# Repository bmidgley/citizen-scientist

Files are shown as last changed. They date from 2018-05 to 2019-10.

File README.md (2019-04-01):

# citizen-scientist

Monitor air quality and automatically share the collected data using inexpensive hardware.

[OpenWest slides](https://docs.google.com/presentation/d/14199zjeJYKTTuAwEFpema6mJRyAuVe0BQ5JEuAFFPP4/edit?usp=sharing) show how to build the project, including slide 24 with wiring explanation.

## Setup

Install [arduino](https://www.arduino.cc/en/Main/Software) 1.8.2 or newer

Install serial driver from [vendor drivers](https://www.silabs.com/products/development-tools/software/usb-to-uart-bridge-vcp-drivers)

Set up [esp8266 runtime](http://esp8266.github.io/Arduino/versions/2.0.0/doc/installing.html) for arduino

Open geothunk.ino in arduino and select board. Tools->Board->NodeMCU 1.0 (ESP-12E Module)

Libraries: sketch->include library->manage libraries
* WiFiManager (0.14.x)
* ArduinoJson (5.x.x)
* PubSubClient (2.x.x)
* "ESP8266 and ESP32 Oled Driver for SSD1306 display" (4.x.x)
* Esp8266TrueRandom (wget https://github.com/marvinroger/ESP8266TrueRandom/archive/master.zip; sketch->include library->Add .zip Library)

Plug in board and choose the port. On mac: Tools->Port->/dev/cu.SLAB_USBtoUART (Reboot and check your USB cable is a full power+data cable if the port isn't available.)

Hit the upload button.

Reboot the board and use your phone to connect to the Geothunk-XXX access point. In the captive portal screen, set the password for your access point. Hit save. There is a [youtube video](https://www.youtube.com/watch?v=-iKyWOWEP4E&t=4s) to show this in practice.

If you're on the same access point as the sensor, you should be able to see graphs for your measurements by clicking its [geothunk.local](http://geothunk.local) mdns link. If mdns isn't working or you have multiple sensors, point a browser at the IP address displayed on the device instead.

Register and agree to share your data with our [agreement](https://docs.google.com/forms/d/e/1FAIpQLScs9sQVZbnWg0XCuS6sA2pAkzf4LLobDE_Wj_pccsHPoGVKmw/viewform)

## Contributors

* Brad Midgley wrote the firmware and built the sensor
* Tim Harper updated the firmware with refactors, overflow protection, improved sensor listener
* Dorian Tolman designed the case

Parts:
* Esp8266 [D-Duino](https://www.aliexpress.com/item/new-NODEMCU-wifi-NodeMCU-forArduino-ESP8266-wemos-for-OLED/32802190441.html)
* [DHT22](https://www.aliexpress.com/wholesale?SearchText=dht22) (3-wire package)
* [PMS3003](https://www.aliexpress.com/item/Laser-PM2-5-DUST-SENSOR-PMS3003-High-precision-laser-dust-concentration-sensor-digital-dust-particles-G3/32371229255.html)

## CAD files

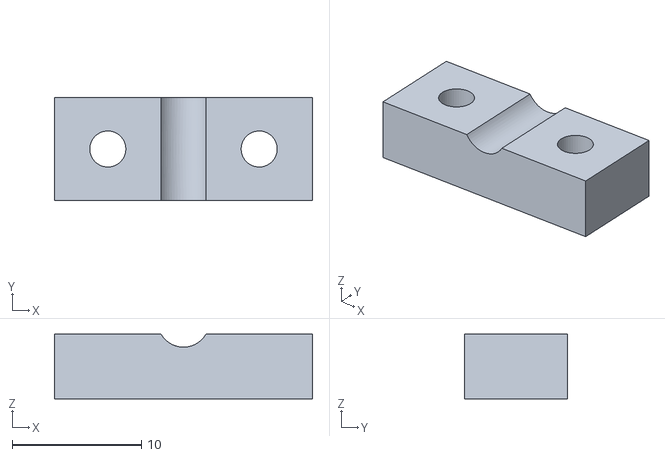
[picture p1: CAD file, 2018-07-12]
prints/v2/cord clamp.stl
20.0 x 8.00 x 5.00

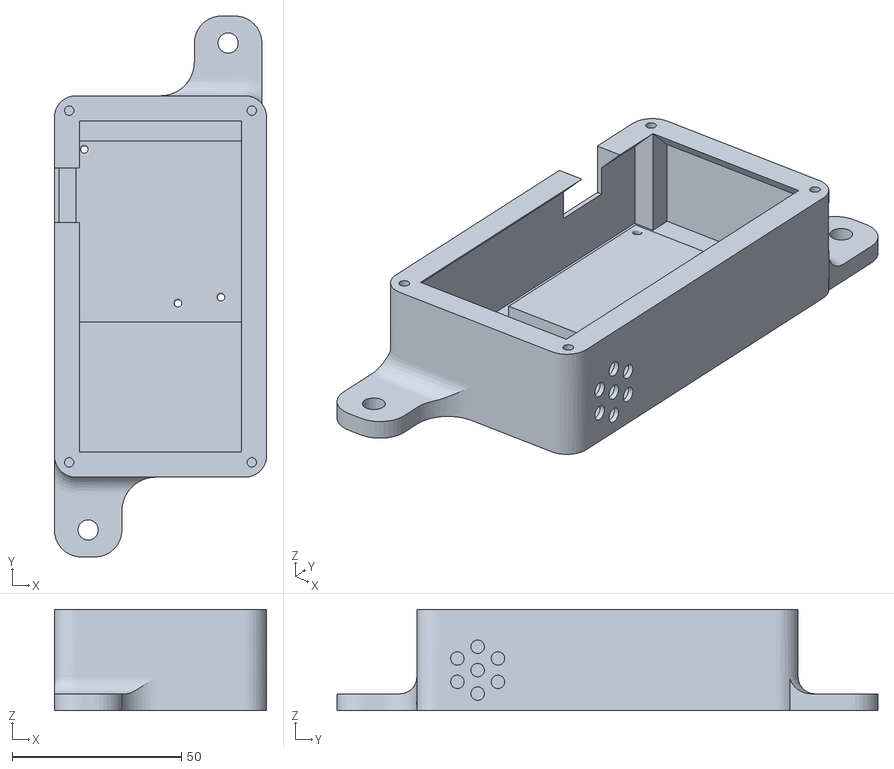
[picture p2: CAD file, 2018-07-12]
prints/v2/base.stl
62.8 x 160.0 x 30.0

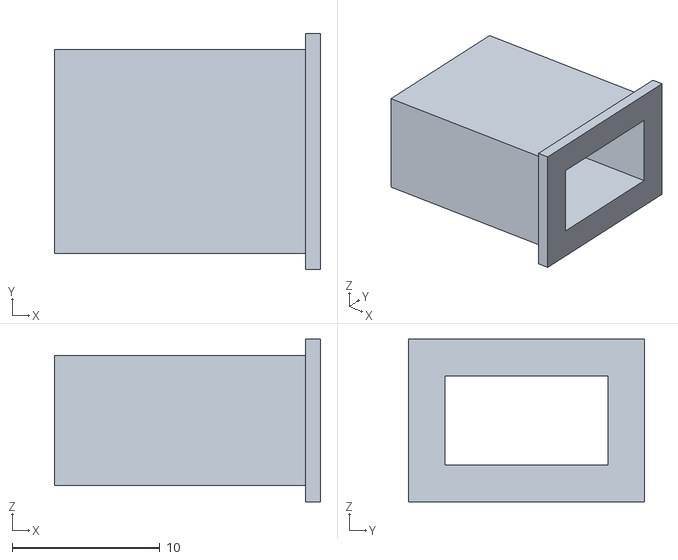
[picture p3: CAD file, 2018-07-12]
prints/v2/vent port.stl
18.0 x 16.0 x 11.0

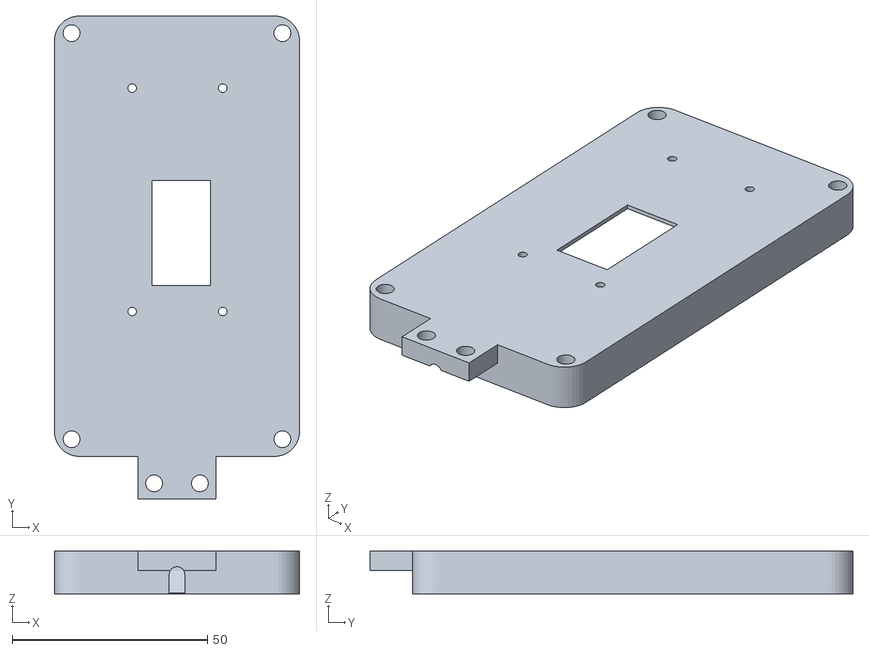
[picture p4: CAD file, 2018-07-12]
prints/v2/top.stl
62.8 x 123.7 x 11.0

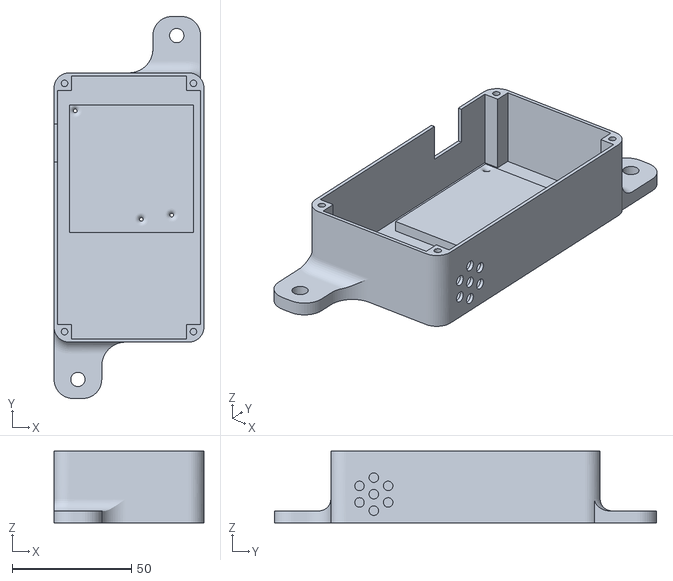
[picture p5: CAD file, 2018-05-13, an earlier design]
prints/v1/AirT Base B.stl
62.8 x 160.0 x 30.0

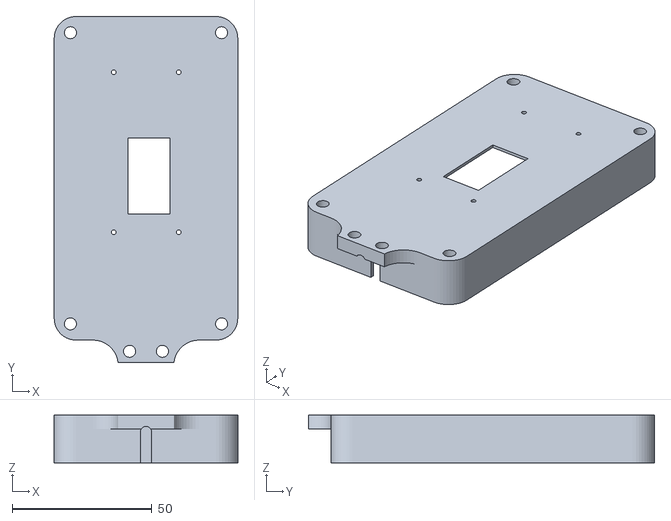
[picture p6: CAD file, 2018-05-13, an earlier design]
prints/v1/AirT Top B.stl
65.6 x 123.6 x 17.0

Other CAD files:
prints/v1/AirT Clamp B.stl
prints/v1/AirT Vent Port BB.stl

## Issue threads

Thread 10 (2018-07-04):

Device reporting 4000+ -- check sensor

bmidgley, 2018-07-04:

bmidgley, 2018-07-08:
Power cycling the device corrected this and it hasn't happened again in a few days. We need to automate the reset.

Closed 2018-07-08.

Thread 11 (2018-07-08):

Reset the sensor in response to a bus message, on a schedule, or when it reports questionable readings

bmidgley, 2018-07-08:

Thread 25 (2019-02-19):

Slow wifi connections time out and go into AP mode

bmidgley, 2019-02-19:
If the wifi connection takes a long time or is unreliable, the device goes into AP mode. Combined with reset cycles causes the device to be unreliable.

There should be a way to lock the wifi or make a long timeout.

I think I'd prefer a configuration option to lock the wifi and never enter AP mode.

If the wifi is locked in via flash memory options, then the program button would be required to reset the wifi and get back into AP mode. This will have to work either when associated or when trying to get associated.

I'm not sure we can get into the wifimanager loop, but we could execute this using a connect timeout combined with a test for the button press if you don't mind holding the button for a while to reset it.

timcharper, 2019-02-19:
I don't think my wifi is unreliable :) I'm not sure why the ESP8266 device reboots occasionally, seems it is just a feature of them :)

bmidgley, 2019-02-19:
It didn't always reboot so often. One of the library updates did this, but I prefer reboot to crash. :/

timcharper, 2019-02-19:
Hmm... I'll monitor the serial for a night and see if I can catch the crash. There might be some stack trace info that will help us pinpoint where it's failing.

I've noticed that really-fast-loops cause the device to crash. Not sure why. `while(1) {}` will crash the device but `while(1) { delay(25); }` will run forever.

timcharper, 2019-02-19:
@bmidgley what would you think if we worked around it? We could have our own code check to see if an AP is persisted, first, and then try and connect to it if so, and then breaking out of the loop in to AP mode if the button is pressed.

For the meantime, I think it seems reasonable to take the case apart and reset if changing AP's; that's not a frequent occurrence. Further we could expose an endpoint which, when hit, reboots the device in AP / config mode.

timcharper, 2019-02-25:
#29 addresses this

Closed 2019-03-07.

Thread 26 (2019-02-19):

Program button can't be pressed using the current 3d printed case

bmidgley, 2019-02-19:
This is a hardware bug! I'll get exact measurements so we can print a pinhole in the right spot and use a pin to hit this button.

I've tried this out and found I broke the microusb connection to the board. So we will need to be sure the board is both connected solidly to the faceplate and also add a little loop in the usb cable so if it does wiggle, it won't put pressure on the connector.

bmidgley, 2019-02-19:
I measure 72.5mm from the left side and 22mm from the top hits the center of the button. We should have a hole that is 1 to 1.5mm diameter. Should be big enough to get a sharp pin in but not so big that we might miss the button.

bmidgley, 2019-02-19:
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

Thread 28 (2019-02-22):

WeMos DHT sensor regression with 7a0b17b

timcharper, 2019-02-22:
After upgrading my WeMos geothunk sensor (the one with the built-in display) to the latest master, I noted that the DHT temperature readings would fail frequently. I traced it down to commit 7a0b17b45ff842c71e1ffa096dcdffaaa0ece5c0, specifically the following change:

```diff
diff --git a/geothunk/geothunk.ino b/geothunk/geothunk.ino
index d2b9a7e..99801b4 100644
--- a/geothunk/geothunk.ino
+++ b/geothunk/geothunk.ino
@@ -296,9 +296,27 @@ void paint_display(long now) {
   }
   display.setTextAlignment(TEXT_ALIGN_RIGHT);
   display.setFont(ArialMT_Plain_10);
-  display.drawString(display.getWidth(), 34, String("1/2/10=") + String(pm1) + String("/") + String(pm2_5) + String("/") + String(pm10));
-  display.drawString(display.getWidth(), 44, String(humidity) + String("%h"));
-  display.drawString(display.getWidth(), 54, String(temperature) + String("°C"));
+
+  String pmValues = String("1/2/10=");
+  String humidityString;
+  String temperatureString;
+
+  if (pmOverdue(now))
+    pmValues = pmValues + String("E/E/E");
+  else
+    pmValues = pmValues + String(pm1) + String("/") + String(pm2_5) + String("/") + String(pm10);
+
+  if (dhtOverdue(now)) {
+    humidityString = String("E");
+    temperatureString = String("E");
+  } else {
+    humidityString = String(humidity);
+    temperatureString = String(temperature);
+  }
+  display.drawString(display.getWidth(), 34, pmValues);
+  display.drawString(display.getWidth(), 44, humidityString + String("%h"));
+  display.drawString(display.getWidth(), 54, temperatureString + String("°C"));
+
   display.setTextAlignment(TEXT_ALIGN_LEFT);
   if (hours < 24)
     uptime = String(hours) + String("h");
```

timcharper, 2019-02-22:
I don't fully understand why this is broken, but I suspect it has something to do with `String pmValues = String("1/2/10=");` followed by `pmValues = pmValues + ...`. Perhaps the String class is doing some auto management of memory when it is freed from the stack, and this pattern of usage is causing it to fail.

timcharper, 2019-02-22:
This works:

```diff
diff --git a/geothunk/geothunk.ino b/geothunk/geothunk.ino
index d2b9a7e..ca401a1 100644
--- a/geothunk/geothunk.ino
+++ b/geothunk/geothunk.ino
@@ -296,9 +296,27 @@ void paint_display(long now) {
   }
   display.setTextAlignment(TEXT_ALIGN_RIGHT);
   display.setFont(ArialMT_Plain_10);
-  display.drawString(display.getWidth(), 34, String("1/2/10=") + String(pm1) + String("/") + String(pm2_5) + String("/") + String(pm10));
-  display.drawString(display.getWidth(), 44, String(humidity) + String("%h"));
-  display.drawString(display.getWidth(), 54, String(temperature) + String("°C"));
+
+  char buffer[64];
+
+  if (pmOverdue(now))
+    strncpy(buffer, "1/2/10=E/E/E", sizeof(buffer));
+  else
+    snprintf(buffer, sizeof(buffer), "1/2/10=%d/%d/%d", pm1, pm2_5, pm10);
+  display.drawString(display.getWidth(), 34, buffer);
+
+  if (dhtOverdue(now)) {
+    strncpy(buffer, "E", sizeof(buffer));
+  } else {
+    snprintf(buffer, sizeof(buffer), "%d%%h", humidity);
+  }
+  display.drawString(display.getWidth(), 44, buffer);
+
+  if (!dhtOverdue(now)) {
+    snprintf(buffer, sizeof(buffer), "%d°C", temperature);
+  }
+  display.drawString(display.getWidth(), 54, buffer);
+
   display.setTextAlignment(TEXT_ALIGN_LEFT);
   if (hours < 24)
     uptime = String(hours) + String("h");
```

bmidgley, 2019-02-22:
Nice find. It is unnerving to have a really complete and complex SDK and not know if it's safe to use. Will have to do it carefully.

timcharper, 2019-02-22:
It's not a regression with 7a0b17b, it's the hardware. Probably some timing issue. I found that simply increasing the tolerance for a "faster" high pull allows it to measure consistently.

https://github.com/timcharper/SimpleDHT/commit/44d730c19a1cbf79668dddef0c92bb6aad8109bd

timcharper, 2019-02-22:
https://github.com/winlinvip/SimpleDHT/issues/35

timcharper, 2019-02-25:
I'm closing this; I tried with a new board and a new DHT22 sensor, and the issue is gone. It may have just been the board. It is nice to know that reducing the timing threshold in SimpleDHT from 30 to 20 when seeing an error `SimpleDHTErrStartLow`.

Closed 2019-02-25.

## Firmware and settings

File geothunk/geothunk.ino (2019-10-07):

//#define SPI_DISPLAY
//#define SH1106_DISPLAY
//#define NO_AUTO_SWAP
//#define DEBUG
#ifdef DEBUG
#define NO_AUTO_SWAP
#endif

#ifdef SPI_DISPLAY
#define NO_AUTO_SWAP
#endif

#include <FS.h>
#include <ESP8266WiFi.h>
#include <DNSServer.h>
#include <ESP8266WebServer.h>
#include <WiFiManager.h>
#include <PubSubClient.h>
#include "SSD1306Spi.h"
#include "SH1106.h"
#include "SSD1306.h"
#include "ESP8266TrueRandom.h"
#include <ArduinoJson.h>
#include <ESP8266mDNS.h>
#include <ArduinoOTA.h>
#include <ESP8266httpUpdate.h>
#include <WiFiClientSecure.h>
#include <time.h>
#include <Servo.h>
#include "PmsSensorReader.h"
#include "Presentation.h"
#include "UniversalDHT.h"

int pinDHT = D3;
UniversalDHT dht(pinDHT);

// use arduino library manager to get libraries
// sketch->include library->manage libraries
// WiFiManager, ArduinoJson, PubSubClient, ArduinoOTA, "ESP8266 and ESP32 Oled Driver for SSD1306 display"
// wget https://github.com/marvinroger/ESP8266TrueRandom/archive/master.zip
// sketch->include library->Add .zip Library and select master.zip

#define DEFAULT_MDNS_NAME "geothunk"
#define FLASH_BUTTON_PIN 0 // note, this is shared with D3!
#define LED_PIN D4
#define PULSE_PIN D8

bool shouldSaveConfig = false;
unsigned long lastSample = 0;
unsigned long lastReport = 0;
unsigned long lastPmReading = 0;
unsigned long lastDHTReading = 0;
unsigned long lastSwap = 0;
long nextFrame = 0; // Time at which the next frame should be drawn
char msg[200] = "";
char errorMsg[200] = "";
int disconnects = 0;

char mqtt_server[40] = "mqtt.geothunk.com";
char mqtt_port[6] = "8080";
char uuid[64] = "";
char gps_port[10] = "";
char ota_password[10] = "";
char mdns_name[40] = DEFAULT_MDNS_NAME;

char particle_topic_name[128];
char error_topic_name[128];

int sampleGap = 4 * 1000;
int reportGap = 60 * 1000;
int reportExpectedDurationMs = sampleGap * 5;
int byteGPS = -1;
char linea[300] = "";
char comandoGPR[] = "$GPRMC";
int cont = 0;
int bien = 0;
int conta = 0;
int indices[13];
int lats = 1;
int latw = 0;
int latf = 0;
int lngs = 1;
int lngw = 0;
int lngf = 0;

WiFiClientSecure *tcpClient;
PubSubClient *client;
ESP8266WebServer *webServer;
PmsSensorReader pmsSensor;

#ifdef SPI_DISPLAY
SSD1306Spi display(D8, D1, D2); // rst n/c, dc D1, cs D2, clk D5, mosi/di/si D7
#else
#ifdef SH1106_DISPLAY
SH1106 display(0x3c, D1, D2);
#else
SSD1306 display(0x3c, 5, 4);
#endif
#endif

AirData airData;
Presentation presentation(&display, &airData);
Servo myservo;

const char* serverIndex = "<html><head><script type='text/javascript' src='https://cdnjs.cloudflare.com/ajax/libs/smoothie/1.34.0/smoothie.js'></script> <script type='text/javascript' src='https://cdnjs.cloudflare.com/ajax/libs/jquery/3.2.1/jquery.js'></script> <script type='text/Javascript'> \
var sc = new SmoothieChart({ responsive: true, millisPerPixel: 1000, labels: { fontSize: 30, precision: 0 }, grid: { fillStyle: '#6699ff', millisPerLine: 100000, verticalSections: 10 }, yRangeFunction: function(r) { return { min: 0, max: Math.max(30, 10*Math.ceil(0.09 * r.max)) } } }); \
var line1 = new TimeSeries(); var line2 = new TimeSeries(); var line3 = new TimeSeries(); \
sc.addTimeSeries(line1, { strokeStyle:'rgb(180, 50, 0)', fillStyle:'rgba(180, 50, 0, 0.4)', lineWidth:3 }); \
sc.addTimeSeries(line2, { strokeStyle:'rgb(255, 0, 0)', fillStyle:'rgba(255, 0, 0, 0.4)', lineWidth:3 }); \
sc.addTimeSeries(line3, { strokeStyle:'rgb(255, 50, 0)', fillStyle:'rgba(255, 50, 0, 0.4)', lineWidth:3 }); \
$(document).ready(function() { sc.streamTo(document.getElementById('graphcanvas1')); }); \
setInterval(function() { $.getJSON('/stats',function(data){ line1.append(Date.now(), data.pm2); line2.append(Date.now(), data.pm1); if(data.pm10 < 3*data.pm2) line3.append(Date.now(), data.pm10); }); }, 2000); \
</script></head><body>  <canvas id='graphcanvas1' style='width:100%%; height:75%%;'></canvas><p>Register device <a href='https://geothunk.com/devices?d=%s'>online</a>.</p></body></html>";

t_httpUpdate_return update() {
  return ESPhttpUpdate.update("http://updates.geothunk.com/updates/geothunk-" VERSION ".ino.bin");
}

void mqttCallback(char* topic, byte* payload, unsigned int length) {
#ifdef DEBUG
  Serial.print("Message arrived [");
  Serial.print(topic);
  Serial.print("] ");
  for (int i = 0; i < length; i++) {
    char receivedChar = (char)payload[i];
    Serial.print(receivedChar);
  }
  Serial.println();
#endif
}

int mqttConnect() {
  if (WiFi.status() != WL_CONNECTED) {
    return 0;
  }

  if (client->connected()) {
    disconnects = 0;
    return 1;
  }

  if (client->connect(uuid)) {
    client->subscribe("clients");
    return 1;
  } else {
    disconnects += 1;
    return 0;
  }
}

void saveConfigCallback () {
  shouldSaveConfig = true;
}

void to_degrees(char *begin, char *end, int &whole, int &decimal) {
  char copied[20];
  float result;
  strncpy(copied, begin, 10);
  copied[end - begin] = '\0';
  float nmea = atof(copied);
  whole = (int)(nmea / 100);
  nmea -= 100 * whole;
  decimal = (int)(nmea * ( 10000.0 / 60.0));
}

int handle_gps_byte(char byteGPS) {
  linea[conta] = byteGPS;
  conta++;
  if (byteGPS == 13 || conta >= 300) {
    cont = 0;
    bien = 0;
    for (int i = 1; i < 7; i++) {
      if (linea[i] == comandoGPR[i - 1]) {
        bien++;
      }
    }
    if (bien == 6) {
      for (int i = 0; i < 300; i++) {
        if (linea[i] == ',' && cont < 13) {
          indices[cont] = i;
          cont++;
        }
        if (linea[i] == '*') {
          indices[12] = i;
          cont++;
        }
      }
      for (int i = 0; i < 12; i++) {
        switch (i) {
          case 2:
            to_degrees(linea + 1 + indices[i], linea + indices[i + 1], latw, latf);
            break;
          case 3:
            lats = linea[indices[i] + 1] == 'N' ? 1 : -1;
            break;
          case 4:
            to_degrees(linea + 1 + indices[i], linea + indices[i + 1], lngw, lngf);
            break;
          case 5:
            lngs = linea[indices[i] + 1] == 'E' ? 1 : -1;
            break;
        }
      }
    }
    conta = 0;
    for (int i = 0; i < 300; i++) {
      linea[i] = ' ';
    }
  }
}

bool pmOverdue(unsigned long now) {
  return (now - lastPmReading) > reportExpectedDurationMs;
}

bool dhtOverdue(long now) {
  return (now - lastDHTReading) > reportExpectedDurationMs;
}



void handleGPS() {
  if (tcpClient->connected() && tcpClient->available()) handle_gps_byte(tcpClient->read());
}

void measureDHT() {
  float temperature, humidity = 0;
  UniversalDHT::Response response = dht.read(&temperature, &humidity);
#ifdef DEBUG
  if(response.error) {
    Serial.printf("Read DHTxx failed t=%d err=%d\n", response.time, response.error);
  } else {
    Serial.print("Sample OK: ");
    Serial.print((float)temperature); Serial.print(" *C, ");
    Serial.print((float)humidity); Serial.println(" RH%");
    Serial.println();
  }
#endif
  if (!response.error) {
    lastDHTReading = millis();
    airData.humidity = humidity;
    airData.temperature = temperature;
    airData.tempHumidityStatus = AirData_Ok;
  }

  presentation.recordGraphTemperature();
}

boolean loadConfig() {
  if (SPIFFS.begin()) {
    Serial.println("mounted file system");
    if (SPIFFS.exists("/config.json")) {
      Serial.println("found /config.json");
      File configFile = SPIFFS.open("/config.json", "r");
      if (configFile) {
        Serial.println("reading /config.json");
        size_t size = configFile.size();
        std::unique_ptr<char[]> buf(new char[size]);

        configFile.readBytes(buf.get(), size);
        DynamicJsonBuffer jsonBuffer;
        JsonObject& json = jsonBuffer.parseObject(buf.get());
        json.printTo(Serial);
        if (json.success()) {
#ifdef DEBUG
          Serial.println("\nparsed json");
#endif

          if (json.is<char*>("mqtt_server")) strncpy(mqtt_server, json["mqtt_server"].as<char*>(), sizeof(mqtt_server));
          if (json.is<char*>("mqtt_port")) strncpy(mqtt_port, json["mqtt_port"].as<char*>(), sizeof(mqtt_port));
          if (json.is<char*>("mdns_name")) strncpy(mdns_name, json["mdns_name"].as<char*>(), sizeof(mdns_name));
          if (json.is<char*>("gps_port")) strncpy(gps_port, json["gps_port"].as<char*>(), sizeof(gps_port));
          if (json.is<char*>("ota_password")) strncpy(ota_password, json["ota_password"].as<char*>(), sizeof(ota_password));
          if (json.is<char*>("uuid")) strncpy(uuid, json["uuid"].as<char*>(), sizeof(uuid));
          return true;
        } else {
          Serial.println("failed to load json config");
        }
      }
    }
  } else {
    Serial.println("failed to mount FS");
  }
  return false;
}

void configureAP() {
  char ap_name[64] = "";
  byte uuidNumber[16];
  byte uuidCode[16];
  WiFiManager wifiManager;

  ESP8266TrueRandom.uuid(uuidCode);
  ESP8266TrueRandom.uuidToString(uuidCode).toCharArray(ota_password, 7);

  WiFiManagerParameter custom_mqtt_server("server", "mqtt server", mqtt_server, sizeof(mqtt_server));
  WiFiManagerParameter custom_mqtt_port("port", "mqtt port", mqtt_port, sizeof(mqtt_port));
  WiFiManagerParameter custom_mdns_name("name", "Hostname (optional)", mdns_name, sizeof(mdns_name));
  WiFiManagerParameter custom_gps_port("gps_port", "GPS server port (optional)", gps_port, sizeof(gps_port));
  WiFiManagerParameter custom_ota_password("ota_password", "OTA password (optional)", ota_password, sizeof(ota_password));

  wifiManager.setSaveConfigCallback(saveConfigCallback);

  wifiManager.addParameter(&custom_mqtt_server);
  wifiManager.addParameter(&custom_mqtt_port);
  wifiManager.addParameter(&custom_mdns_name);
  wifiManager.addParameter(&custom_gps_port);
  if (*ota_password == 0) {
    Serial.println("generating ota_password");
    wifiManager.addParameter(&custom_ota_password);
    saveConfigCallback();
  }
  if (*uuid == 0) {
    Serial.println("generating uuid");
    ESP8266TrueRandom.uuid(uuidNumber);
    ESP8266TrueRandom.uuidToString(uuidNumber).toCharArray(uuid, 64);
    saveConfigCallback();
  }

  snprintf(ap_name, sizeof(ap_name), "Geothunk-%d", ESP8266TrueRandom.random(100, 1000));
  Serial.printf("Configure by connecting to AP %s\n", ap_name);

  wifiManager.setTimeout(600);
  wifiManager.setBreakAfterConfig(true);
  presentation.paintServingAp(String(ap_name));

  digitalWrite(LED_PIN, LOW);
  boolean connected = false;

  while (!connected) {
    connected = wifiManager.startConfigPortal(ap_name);
    Serial.println("stored wifi connected");
    WiFi.setAutoConnect(true);

    strcpy(mqtt_server, custom_mqtt_server.getValue());
    strcpy(mqtt_port, custom_mqtt_port.getValue());
    strncpy(mdns_name, custom_mdns_name.getValue(), sizeof(mdns_name));
    strcpy(gps_port, custom_gps_port.getValue());

    if (shouldSaveConfig) {
      shouldSaveConfig = false;
      Serial.println("saving config");
      DynamicJsonBuffer jsonBuffer;
      JsonObject& json = jsonBuffer.createObject();
      json["mqtt_server"] = mqtt_server;
      json["mqtt_port"] = mqtt_port;
      json["mdns_name"] = mdns_name;
      json["gps_port"] = gps_port;
      json["ota_password"] = ota_password;
      json["uuid"] = uuid;

      File configFile = SPIFFS.open("/config.json", "w");
      if (!configFile) {
        Serial.println("failed to open config file for writing");
      }

      json.printTo(Serial);
      Serial.println("");
      json.printTo(configFile);
      configFile.close();
      if (WiFi.status() != WL_CONNECTED) {
        /* WiFi manager on NodeMCU seems to always fail to connect to the network after successful configuration, no matter how
         * long you wait. It should connect after a reboot resolves.
         */
        ESP.restart();
      }
    }

    measureDHT();

  };

  digitalWrite(LED_PIN, HIGH);
}

int timeInState(int pin, int state, int timeout) {
  if (digitalRead(pin) != state)
    return 0;

  unsigned long start = millis();
  unsigned long now = start;
  while ((digitalRead(pin) == state) && ((now - start) < timeout)) {
    yield(); // appease the watchdog
    now = millis();
  }
  return now - start;
}

void setup() {
  airData.pmStatus = AirData_Uninitialized;
  airData.tempHumidityStatus = AirData_Uninitialized;

  Serial.begin(9600);
  Serial.println("\n Starting");
  pinMode(FLASH_BUTTON_PIN, INPUT);
  pinMode(LED_PIN, OUTPUT);
  pinMode(PULSE_PIN, OUTPUT);
  tone(PULSE_PIN, 40);
  WiFi.printDiag(Serial);
  myservo.attach(D0);

  display.init();
#ifndef SPI_DISPLAY
  display.flipScreenVertically();
#endif
  display.setContrast(255);
  display.clear();


  boolean configWasLoaded = loadConfig();

  if (configWasLoaded && ((WiFi.SSID() != NULL) && (WiFi.SSID().length() > 0))) {
    Serial.print("Reconnecting to last saved access point, ");
    Serial.println(WiFi.SSID());
    //trying to fix connection in progress hanging
    WiFi.begin();
    presentation.paintConnectingWifi();
    while (WiFi.status() != WL_CONNECTED) {
      yield(); // prevent watchdog from restarting controller
      if (timeInState(FLASH_BUTTON_PIN, LOW, 15000) >= 1000) {
        Serial.println("Resetting WiFi credentials to put back in config mode");
        WiFi.disconnect();
        delay(500);
        ESP.restart();
      };
    }
    digitalWrite(LED_PIN, HIGH);
  } else {
    configureAP();
  }

  presentation.paintConnectingMqtt(millis());

  int mqtt_port_int = strtoul(mqtt_port, NULL, 10);
  Serial.printf("Connecting to mqtt on %s, port %i\n", mqtt_server, mqtt_port_int);
  client = new PubSubClient(mqtt_server, mqtt_port_int, *(new WiFiClient()));
  client->setCallback(mqttCallback);
  mqttConnect();

  for (int i = 0; i < 300; i++) {
    linea[i] = ' ';
  }
  tcpClient = new WiFiClientSecure();
  tcpClient->connect(WiFi.gatewayIP(), atoi(gps_port));
  snprintf(particle_topic_name, sizeof(particle_topic_name), "%s/particles", uuid);
  snprintf(error_topic_name, sizeof(error_topic_name), "%s/errors", uuid);

  Serial.printf("publishing data on %s\n", particle_topic_name);
  Serial.printf("publishing errors on %s\n", error_topic_name);

  Serial.printf("ota_password is %s\n", ota_password);
#ifndef DEBUG
  ArduinoOTA.setPassword(ota_password);
#endif

  ArduinoOTA.onProgress([](unsigned int progress, unsigned int total) {
    Serial.printf("Progress: %u%%\r", (progress / (total / 100)));
  });
  ArduinoOTA.onError([](ota_error_t error) {
    Serial.printf("Error[%u]: ", error);
    if (error == OTA_AUTH_ERROR) Serial.println("Auth Failed");
    else if (error == OTA_BEGIN_ERROR) Serial.println("Begin Failed");
    else if (error == OTA_CONNECT_ERROR) Serial.println("Connect Failed");
    else if (error == OTA_RECEIVE_ERROR) Serial.println("Receive Failed");
    else if (error == OTA_END_ERROR) Serial.println("End Failed");
  });
  ArduinoOTA.begin();

  MDNS.begin(mdns_name);
  MDNS.addService("http", "tcp", 80);
  webServer = new ESP8266WebServer(80);
  webServer->onNotFound([]() {
    webServer->send(404, "text/plain", "File not found");
  });
  webServer->on("/", HTTP_GET, []() {
    char response[1600];
    webServer->sendHeader("Connection", "close");
    webServer->sendHeader("Access-Control-Allow-Origin", "*");
    snprintf(response, sizeof(response), serverIndex, uuid);
    webServer->send(200, "text/html", response);
  });
  webServer->on("/stats", HTTP_GET, []() {
    webServer->sendHeader("Connection", "close");
    webServer->sendHeader("Access-Control-Allow-Origin", "*");
    webServer->send(200, "application/json", msg);
  });
  webServer->begin();

  configTime(3 * 3600, 0, "pool.ntp.org", "time.nist.gov");

#ifndef NO_AUTO_SWAP
  Serial.swap();
#endif

}

void pmsSensorLoop(long now) {
#ifdef DEBUG
  if (!Serial.available())
    return;

  Serial.printf("serial: ");
#endif

  while(Serial.available()) {
    unsigned char value = Serial.read();
#ifdef DEBUG
    Serial.printf("%x ", value);
#endif
    if (pmsSensor.offer(value)) {
      lastPmReading = now;
      airData.pm1 = pmsSensor.pm1;
      airData.pm2_5 = pmsSensor.pm2_5;
      airData.pm10 = pmsSensor.pm10;
      airData.pmStatus = AirData_Ok;
      presentation.recordGraphPm2();
    }
  }

#ifdef DEBUG
  Serial.printf("\n");
#endif
}

void loop() {
  handleGPS();
  ArduinoOTA.handle();
  webServer->handleClient();
  client->loop();

  long now = millis();
  pmsSensorLoop(now);

  if (now >= nextFrame) {
    if (dhtOverdue(now)) {
      airData.tempHumidityStatus = AirData_Stale;
    } else {
      airData.tempHumidityStatus = AirData_Ok;
    }

    if (pmOverdue(now)) {
      airData.pmStatus = AirData_Stale;
    } else {
      airData.pmStatus = AirData_Ok;
    }

    nextFrame = now + 64; // 1000 / 64 = ~15 fps
    presentation.paintDisplay(now);
  }

  if (now - lastSample > sampleGap) {
    lastSample = now;

    measureDHT();

    myservo.write(map(pmsSensor.pm2_5, 0, 30, 180, 0));

    if (!tcpClient->connected() && atoi(gps_port) > 0) tcpClient->connect(WiFi.gatewayIP(), atoi(gps_port));

    long earlierLastReading = lastPmReading < lastDHTReading ? lastPmReading : lastDHTReading;
    snprintf(msg, sizeof(msg), "{\"pm2\":%u,\"pm1\":%u,\"pm10\":%u,\"l\":%s%d.%d,\"n\":%s%d.%d,\"u\":%u,\"t\":%0.1f,\"h\":%0.1f}",
             pmsSensor.pm2_5, pmsSensor.pm1, pmsSensor.pm10, lats > 0 ? "" : "-", latw, latf, lngs > 0 ? "" : "-", lngw, lngf, earlierLastReading / 60000, airData.temperature, airData.humidity);

    *errorMsg = 0;
    if (lastSample - lastPmReading > 30000) {
      snprintf(errorMsg, sizeof(errorMsg), "{\"lastSample\": %u, \"lastPmReading\": %u}", lastSample, lastPmReading);
#ifndef NO_AUTO_SWAP
      if (now - lastSwap > 60000) {
        Serial.println("swapping from here");
        Serial.flush();
        Serial.swap();
        Serial.println("swapped to here");
        lastSwap = now;
      }
#endif
    }
  }

  if (now - lastReport > reportGap && mqttConnect()) {
    lastReport = now;

    if(!client->publish(particle_topic_name, msg))
      Serial.printf("failed to send %s", msg);
    if (*errorMsg) {
      client->publish(error_topic_name, errorMsg);
      *errorMsg = '\0';
    }
  }

  // restart once per day
  if (now > 1000 * 60 * 60 * 24) {
    ESP.restart();
  }
}

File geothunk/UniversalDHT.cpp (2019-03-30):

/*
  Universal auto-detecting DHT11 or DHT22 sensor.

  Copyright (c) 2019 Tim Harper

  https://github.com/timcharper

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
  THE SOFTWARE IS PROVIDED "AS IS", WITHOUT WARRANTY OF ANY KIND, EXPRESS OR
  IMPLIED, INCLUDING BUT NOT LIMITED TO THE WARRANTIES OF MERCHANTABILITY,
  FITNESS FOR A PARTICULAR PURPOSE AND NONINFRINGEMENT. IN NO EVENT SHALL THE
  AUTHORS OR COPYRIGHT HOLDERS BE LIABLE FOR ANY CLAIM, DAMAGES OR OTHER
  LIABILITY, WHETHER IN AN ACTION OF CONTRACT, TORT OR OTHERWISE, ARISING FROM,
  OUT OF OR IN CONNECTION WITH THE SOFTWARE OR THE USE OR OTHER DEALINGS IN THE
  SOFTWARE.
*/

/**
 * This module is a rewrite of SimpleDHT: https://github.com/winlinvip/SimpleDHT
 *
 * SimpleDHT is Copyright (c) 2016-2017 winlin, and is also licensed MIT
 */

#include "UniversalDHT.h"

UniversalDHT::UniversalDHT(int pin) {
  this->pin = pin;
}

bool waitWhileValue(int pin, byte value) {
  unsigned long time_start = micros();
  long time = 0;

  while (digitalRead(pin) == value) {
    delayMicroseconds(6);
    time = micros() - time_start;
    if ((time < 0) || (time > VALUE_TIMEOUT)) {
      return false;
    }
  }
  return true;
}

UniversalDHT::Response parseDHT11(short rawTemperature, short rawHumidity, float* ptemperature, float* phumidity) {
  UniversalDHT::Response ret = {UniversalDHT::Response::success, 0};

  if (ptemperature) {
    *ptemperature = (float)(rawTemperature>>8);
  }
  if (phumidity) {
    *phumidity = (float)(rawHumidity>>8);
  }
  return ret;
}

UniversalDHT::Response parseDHT22(short rawTemperature, short rawHumidity, float* ptemperature, float* phumidity) {
  UniversalDHT::Response ret = {UniversalDHT::Response::success, 0};

  if (ptemperature) {
    *ptemperature = (float)((rawTemperature & 0x8000 ? -1 : 1) * (rawTemperature & 0x7FFF)) / 10.0;
  }
  if (phumidity) {
    *phumidity = (float)rawHumidity / 10.0;
  }

  return ret;
}

UniversalDHT::Response UniversalDHT::read(float* ptemperature, float* phumidity) {
  RawReading reading;
  Response ret = sample(&reading);
  if (ret.error) return ret;


  byte expect = reading.humidity16 + reading.humidity8 + reading.temperature16 + reading.temperature8;
  if (reading.checksum != expect) {
    ret.error = UniversalDHT::Response::errDataChecksum;
    return ret;
  }

  short rawHumidity = ((short)reading.humidity16 << 8) | reading.humidity8;;
  short rawTemperature = ((short)reading.temperature16 << 8) | reading.temperature8;;

  /**
   * DHT11 min humidity sensitivity is 20 and is reported as 20, 0
   * DHT22 max humidity is 100 and is reported as 3, 232
   * A value of 4, x or greater can be safely assumed as a DHT11 reading (it would be 102.4% humidity interpretted as DHT22)
   */
  if (reading.humidity16 > 4)
    return parseDHT11(rawTemperature, rawHumidity, ptemperature, phumidity);
  else
    return parseDHT22(rawTemperature, rawHumidity, ptemperature, phumidity);
}


inline int advance(long &last_frame, long &next_frame) {
  last_frame = next_frame;
  next_frame = micros();
  return next_frame - last_frame;
}

UniversalDHT::Response UniversalDHT::sample(RawReading *reading) {
  long lf, nf = 0;
  Response ret = {Response::success, 0};

  // https://www.sparkfun.com/datasheets/Sensors/Temperature/DHT22.pdf
  pinMode(pin, OUTPUT);
  digitalWrite(pin, LOW);            // Step 1: send start signal
  delay(20);                         // DHT11: at least 18ms; DHT22: at least 1ms

  // Pull high and set to input, before wait 40us.
  digitalWrite(pin, HIGH);           // 2.
  delayMicroseconds(25);             // specs [2]: 20-40us

  advance(lf, nf);

  // pin_mode change can take variable amounts of time to return; starting our timer measurement before calling pinMode
  // is paramount for reliable timings
  pinMode(pin, INPUT);

  // DHT11 starting:
  //    1. PULL LOW 80us
  //    2. PULL HIGH 80us
  waitWhileValue(pin, LOW);
  int t = advance(lf, nf);
  if (t < 30) {                    // specs [2]: 80us
    ret.time = t;
    ret.error = Response::errStartLow;
    return ret;
  }

  waitWhileValue(pin, HIGH);             // 2.
  t = advance(lf, nf);
  if (t < 50) {                    // specs [2]: 80us
    ret.time = t;
    ret.error = Response::errStartHigh;
    return ret;
  }


  byte *ptr = (byte *)reading;
  // DHTxx data transmission:
  //    1. 1bit start, PULL LOW 50us
  //    2. PULL HIGH:
  //         - 26-28us, bit(0)
  //         - 70us, bit(1)
  for (byte byte_idx = 0; byte_idx < sizeof(RawReading); byte_idx ++) {
    ptr = (byte*)reading + byte_idx;
    *ptr = 0;
    for (signed char bit_idx = 7; bit_idx >= 0; bit_idx --) {
      waitWhileValue(pin, LOW);          // 1.
      t = advance(lf, nf);
      if (t < 24) {                    // specs says: 50us
        ret.time = t;
        ret.error = Response::errDataLow;
        return ret;
      }

      // read a bit
      waitWhileValue(pin, HIGH);              // 2.
      t = advance(lf, nf);
      if (t < 11) {                     // specs say: 26-28us
        ret.time = t;
        ret.error = Response::errDataRead;
        return ret;
      }

      *ptr = *ptr | ((t > 40 ? 1 : 0) << bit_idx);     // specs: 26-28us -> 0, 70us -> 1
    }
  }

  // DHT11 EOF:
  //    1. PULL LOW 50us.
  waitWhileValue(pin, LOW);                     // 1.
  t = advance(lf, nf);
  if (t < 24) {                           // specs say: 50us
    ret.time = t;
    ret.error = Response::errDataEOF;
  }

  return ret;
}

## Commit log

2017-05-06 reading from air sensor
2017-05-21 reconfigure requires a long buttonpress
2017-05-23 fix topic name, add error topic
    [geothunk.ino]
2017-07-12 print topic names
2017-07-18 create ota password, reset instructions, less update poll info
    [geothunk.ino]
2017-07-24 swap to the second port if no data arrives for alternate wiring
    [geothunk.ino]
2017-07-31 display temperature
2017-07-31 shorten message so mqtt delivers
    [geothunk.ino]
2017-08-18 basic os update button
2017-12-25 fix reversed logic for report gap
    [geothunk.ino]
2017-12-25 shorten message to fit in limit
    [geothunk.ino]
2017-12-25 do not reboot to reconnect to bus
    [geothunk.ino]
2017-12-27 print data on http request; pm2.5 is first; better flash reset
    [geothunk.ino]
2018-01-02 spi display support
2018-01-02 flag all debug, no swap option
    [geothunk.ino]
2018-01-02 move temperature sensor to D1 (hardware change!)
2018-01-02 fix compile break for i2c display
    [geothunk.ino]
2018-01-05 use d3 for temp sensor
2018-02-25 flip screen to fit new printed case
    [geothunk.ino]
2018-03-05 do not flip spi display
    [geothunk.ino]
2018-04-09 Revert "turn off wifi diag"
    This reverts commit dc63b3a52ef62be60ffff7ebd0a74f5d00d60ecc.
    [geothunk.ino]
2018-05-13 Add 3d prints and credit
    [AirT Base B.stl, AirT Clamp B.stl, AirT Top B.stl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]
2018-06-28 Set 10 minute timeout to fix config mode
    [geothunk.ino]
2018-06-28 Drive a servo connected to d0 to turn a dial
2018-06-28 Update README.md
    explain driver setup
2018-07-06 Debug sensor
2018-07-12 v2 prints
    [base.stl, cord clamp.stl, top.stl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]
2018-10-26 Bump version and make on-device graph go no smaller than 15ug/m3 scale
2018-12-24 pulse pin
2018-12-26 Add library versions for dependencies
    6.x.x version of ArduinoJSON will not compile
2018-12-29 Newer lcd library flips screen for us
    [geothunk.ino]
2018-12-31 Surface errors in spi display
    If we haven't received a valid reading for PMS3003 or from DHT11, then show E's on the display.
    Also, "u" returned stat is the earliest last update of both DHT11 or PMS3003; malfunction of either sensor will prevent
    the number from progressing.
    [geothunk.ino]
2019-01-01 Use sizeof with snprintf
    Also, fix implicit widening / narrowing for byteGPS
    [geothunk.ino]
2019-01-05 Revert "Newer lcd library flips screen for us"
    This reverts commit cb45a926f348bbc1108baa7a86e9c05a396e7885.
    [geothunk.ino]
2019-01-05 Configure mdns name at setup; remove reconfigure timer
2019-01-15 Use PmsSensorReader class
    One issue with the old reader approach was it expected the data to be
    all available, in a buffer, all at once. There are situations where
    this may not be true. The PmsSensorReader will better handle those
    situations.
    [geothunk.ino]
2019-02-06 Only paint frame when needed
2019-02-06 Turn the LED off when we've connected
2019-02-20 Fix issue in which uuid and mqtt_server config parameters were not read
    Checking truthiness of json["mqtt_server"] and json["uuid"] did not work as expected; if would evaluate to false even
    though there was a key. Using the `is` function behaves predictably.
    [geothunk.ino]
2019-02-24 Bypass WiFiManager if stored SSID and config
    Also, reconfigure via flash button: clear WIFI creds and restart in AP config
    mode if flash is held during wifi connection phase
2019-02-25 Introduce and UniversalDHT to auto-detect DHT11 vs DHT22
    UniversalDHT has improved timing detection; switching pinMode can introduce a variable delay. Starting our timer before
    switching pinMode vastly improved the determistic properties of the sample function.
2019-03-02 Wait for the button to be depressed before restarting
    Holding flash while microcontroller is booting can put it in to actual flash
    mode, whereas we just want to use the button as a special reconfigure
    mechanism.
2019-03-30 Fix transposed values in dht code
    [UniversalDHT.cpp]
2019-10-07 Restart once per day because of memory leaks
    [geothunk.ino]
